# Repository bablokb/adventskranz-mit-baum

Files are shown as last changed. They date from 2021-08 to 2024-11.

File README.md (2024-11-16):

Adventskranz mit Baumornament
=============================

In diesem Projekt geht es um einen Adventskranz aus dem 3D-Drucker.
Statt Kerzen kommen Baum-Ornamente zum Einsatz.

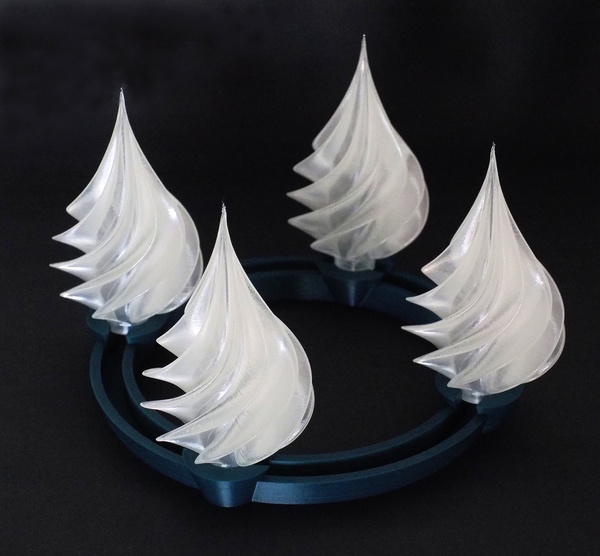
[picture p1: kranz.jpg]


3D-Modelle
----------

Das Modell des Baums (`3D/Ornament.stl.gz`) ist von
<https://www.thingiverse.com/thing:2705104>. Mein Remix
(`3D/Ornament-mit-Basis.stl.gz`) fügt einen
kleinen Stamm hinzu sowie ein Loch im Boden. Das dazugehörige
OpenScad-Programm gibt es auch im Verzeichnis `3D`.
N.B: beide STL-Dateien sind mit gzip komprimiert.

Gedruckt ist das Ornament im Vasenmodus mit naturfarbenem PET. Die
Druckdauer beträgt ca. 2 Stunden pro Ornament (0.2mm Schichtdicke).

Der Kranz ist mit OpenScad entworfen und benötigt 6 Stunden Druckzeit.
Zusätzlich gibt es noch Abdeckungen für die Kabelkanäle. Davon
sind vier notwendig, eine Abdeckung hat einen passenden Ausschnitt
für die Kabelzuführung.

Die Toleranzen sind sehr gering, je nach Drucker und Material
ist hier eine Anpassung notwendig. Dank OpenScad ist das auch
ohne große Vorkenntnisse leicht möglich.

Hardware-Setup
--------------

Das Projekt verwendet diffuse 8mm Neopixels von Adafruit, siehe
<https://www.adafruit.com/product/1734>. Ähnliche LEDs gibt es
auch auf eBay. Die Ansteuerung ist i.a.R. gleich, das Pinout
aber nicht.

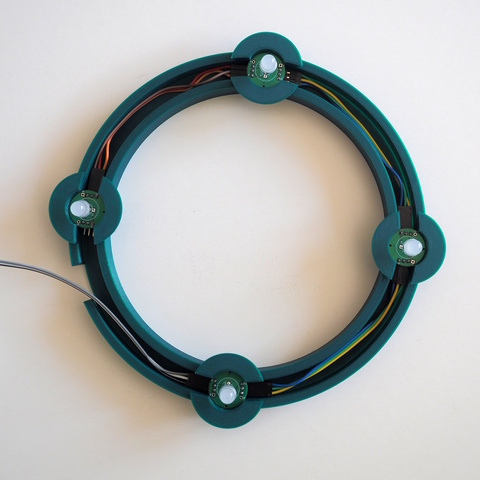
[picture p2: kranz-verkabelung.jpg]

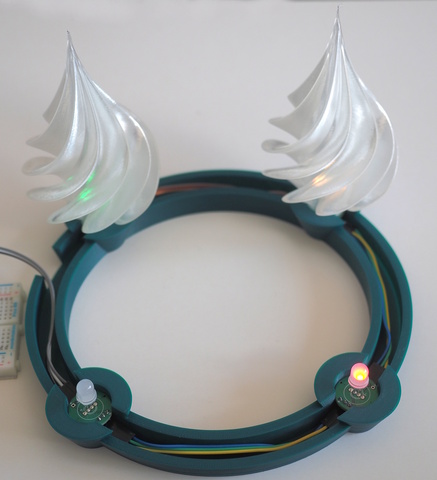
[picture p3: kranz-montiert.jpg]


Jedes Pixel benötigt einen 100nF-Kondensator, das erste Pixel
zusätzlich noch einen 300 Ohm Widerstand in der Datenleitung.

Neopixel benötigen normalerweise 5V (Versorgungsspannung und auf
der Datenleitung). Bei vier Pixel funktioniert es aber i.a.R. auch
mit 3V3. Alle Details zu Neopixel gibt es in dem umfassenden
Handbuch von Adafruit
(<https://learn.adafruit.com/adafruit-neopixel-uberguide>).

Platine
-------

Im Verzeichnis `pcb` gibt es die KiCAD-Quellen für eine passende
Platine. Die Dimensionen der Platine sind exakt auf den Kranz
abgestimmt. Die Miniplatine enthält den Kondensator und den
Widerstand, wobei das Layout so ist, dass die Platine mit oder
ohne Widerstand verwendet werden kann.

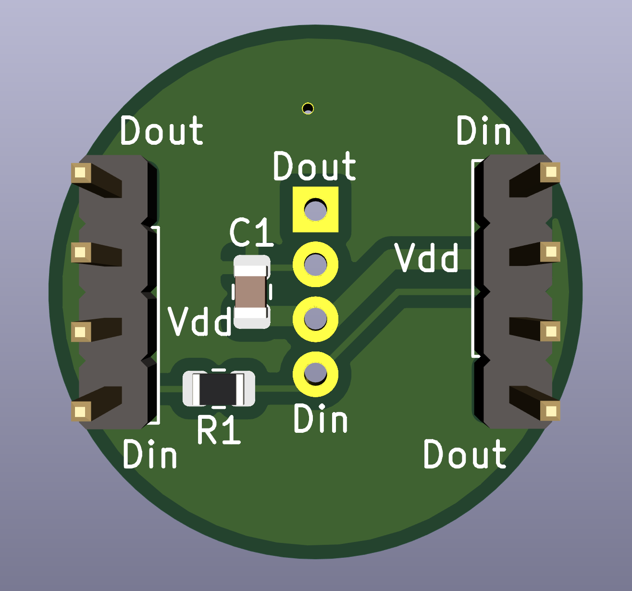
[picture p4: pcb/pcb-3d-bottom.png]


Python-Quellen
--------------

Das Verzeichnis `src_python_btn` enthält ein CircuitPython-Programm für
die Steuerung. Das Programm verwendet einen Taster für das Schalten
der LEDs.

Eine Alternativimplementation ist im Verzeichnis `src_python_sr04`.
Hier kommt ein Distanz-Sensor (HC-SR04) statt des Tasters zum Einsatz.

Eine weitere Alternative ist im Verzeichnis `src_python_touch`
vorhanden. Das Beispiel verwendet die direkte Touch-Unterstützung
durch einen Pin des Mikrokontrollers.

Die vom Projekt mitgelieferten Libs sind auf dem 9.x-Stand und mit
Circuit-Python 9.2.0 mit dem Trinket-M0 getestet.

Attiny85-Quellen
----------------

Im Verzeichnis `src_attiny85` gibt es den Quellcode als C-Programm.

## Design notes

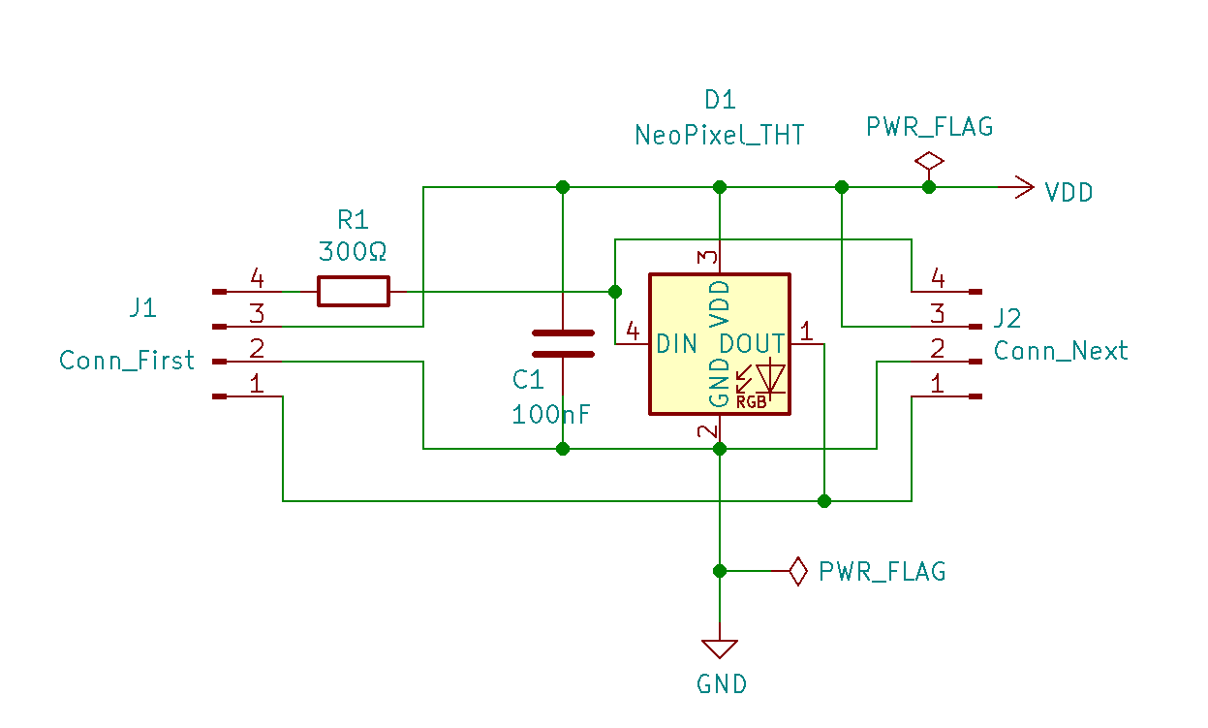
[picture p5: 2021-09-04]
pcb/schematic.png

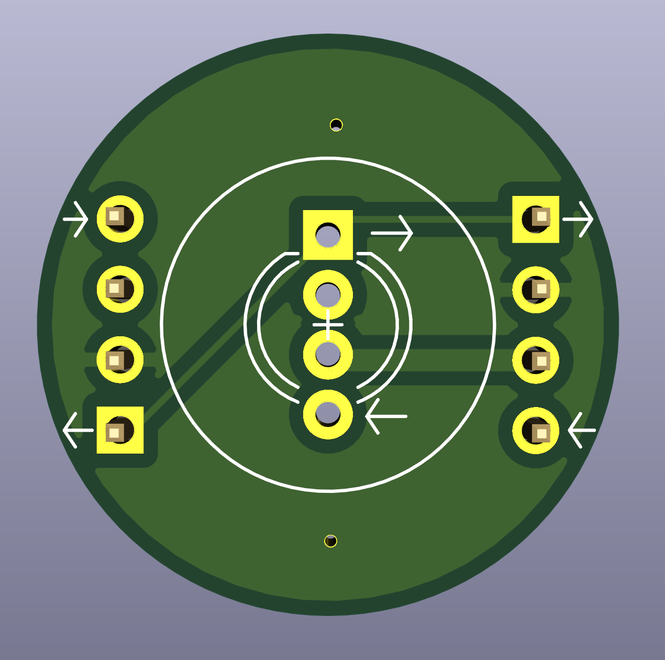
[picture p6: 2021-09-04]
pcb/pcb-3d-top.png

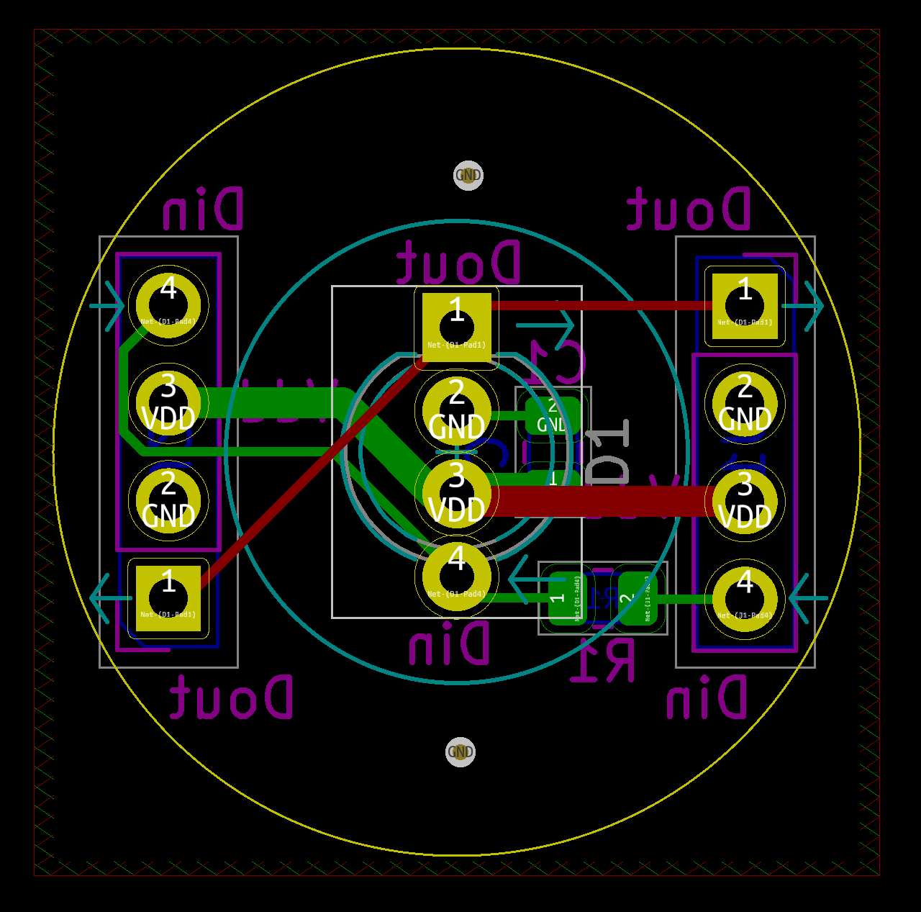
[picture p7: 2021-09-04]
pcb/layout.png

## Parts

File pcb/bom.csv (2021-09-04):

Comment | Designator | Footprint | LCSC
100nF | C1 | Capacitor_SMD:C_0805_2012Metric | C49678
NeoPixel_THT | D1 | LED_THT:LED_D5.0mm-4_RGB_Wide_Pins
Conn_First | J1 | Connector_PinHeader_2.54mm:PinHeader_1x04_P2.54mm_Vertical
Conn_Next | J2 | Connector_PinHeader_2.54mm:PinHeader_1x04_P2.54mm_Vertical
300Ω | R1 | Resistor_SMD:R_0805_2012Metric | C17617

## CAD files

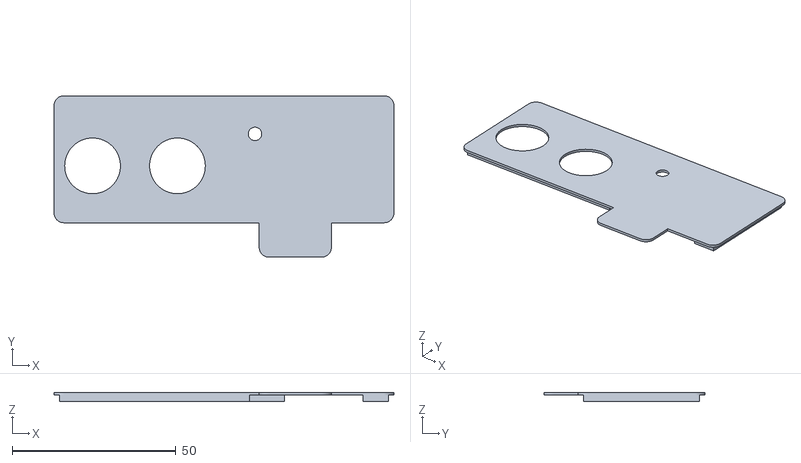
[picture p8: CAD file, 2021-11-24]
3D/steuerung-cover.stl
103.7 x 49.2 x 2.80

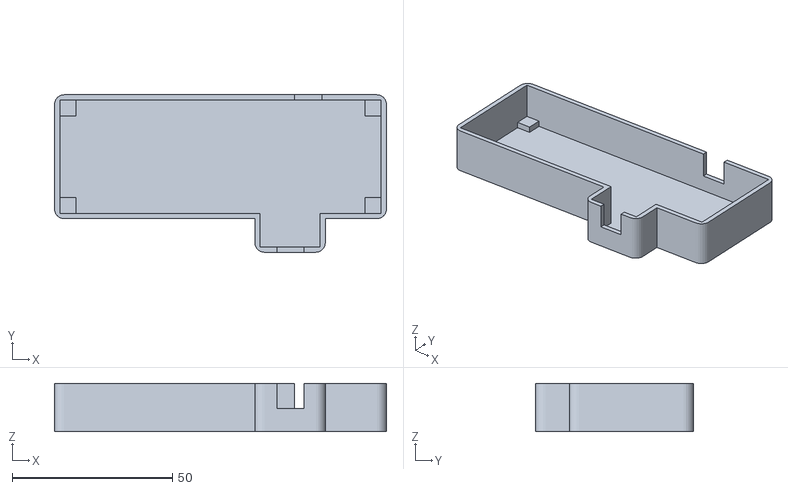
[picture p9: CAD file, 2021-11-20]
3D/steuerung.stl
103.7 x 49.2 x 15.0

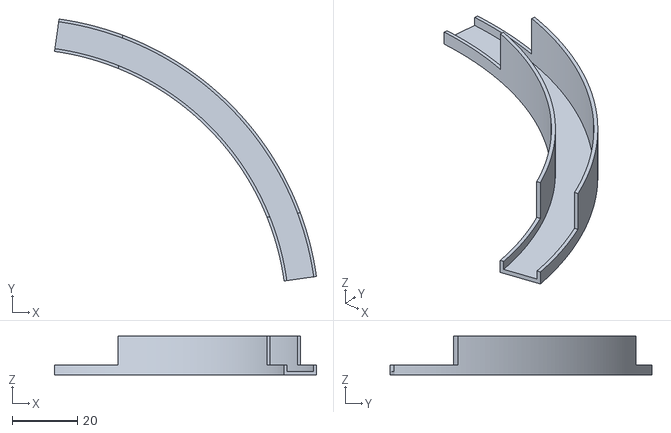
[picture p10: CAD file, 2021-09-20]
3D/abdeckung.stl
80.0 x 80.0 x 11.9

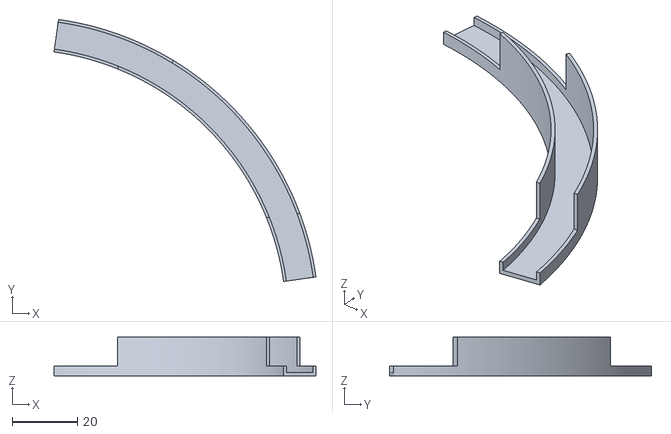
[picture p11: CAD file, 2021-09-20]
3D/abdeckung-mit-ausschnitt.stl
80.0 x 80.0 x 11.9

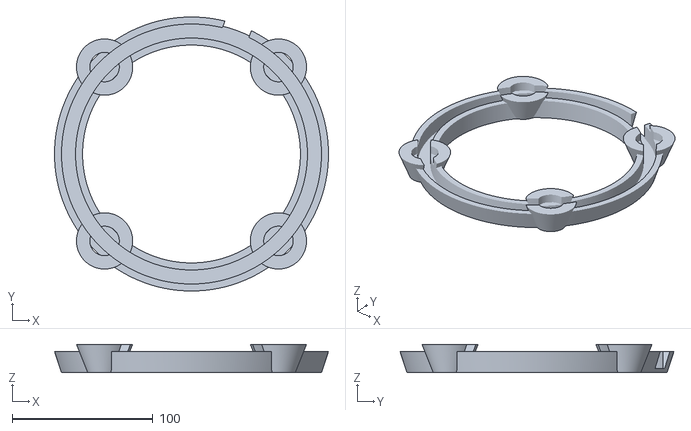
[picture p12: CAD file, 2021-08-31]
3D/kranz.stl
195.0 x 195.0 x 20.0

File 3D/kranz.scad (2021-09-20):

// -----------------------------------------------------------------------------
// 3D-Model (OpenSCAD) Adventskranz.
//
// Author: Bernhard Bablok
// License: GPL3
//
// Website: https://github.com/bablokb/pcb-adventskranz
//
// -----------------------------------------------------------------------------

$fa = 1;
$fs = 0.4;

fuzz = 0.001;

k_b   = 3;             // base
k_h   = 15;            // height
kr_o  = 195/2;         // outer radius
kr_w  = 20;            // width
kr_i  = kr_o - kr_w;   // inner radius
kr_c  = 10;            // cutout-width
k_fac = 0.95;          // slimify-factor
p_h   = 1.6;           // pcb-height

b_h   = 5;             // base height
br_o  = 20;            // base outer radius
br_i  = 10.5;          // base inner radius
b_fac = 0.6;           // slimify-factor (> br_i/br_o)


// --- Generisches Ring Modul   ----------------------------------------------
// Der Faktor gibt an, um wieviel sich die Breite nach unten verjüngt

module ring(o,i,h,fac=1) {
  difference() {
    cylinder(h,o*fac,o);
    translate([0,0,-fuzz]) cylinder(h+2*fuzz,i,i);
  }
}

// --- Basis des Kranz   -----------------------------------------------------
// zusammengesetzt aus einem großen Ring und vier Ringen für die Kerzen

module basis() {
  ring(kr_o,kr_i,k_h,fac=k_fac);
  translate([kr_i+kr_w/2,0,0])  ring(br_o,br_i,k_h+b_h,fac=b_fac);
  translate([-kr_i-kr_w/2,0,0]) ring(br_o,br_i,k_h+b_h,fac=b_fac);
  translate([0,kr_i+kr_w/2,0])  ring(br_o,br_i,k_h+b_h,fac=b_fac);
  translate([0,-kr_i-kr_w/2,0]) ring(br_o,br_i,k_h+b_h,fac=b_fac);
}

// --- Kranz   ---------------------------------------------------------------
// Zusätzliche Ausschnitte für die Platinen je Kerzenhalter sowie
// einem 360°-Kabelkanal

module kranz() {
  difference() {
    basis();
    translate([kr_i+kr_w/2,0,k_h-p_h])  cylinder(b_h+p_h+fuzz,br_i,br_i);
    translate([-kr_i-kr_w/2,0,k_h-p_h]) cylinder(b_h+p_h+fuzz,br_i,br_i);
    translate([0,kr_i+kr_w/2,k_h-p_h])  cylinder(b_h+p_h+fuzz,br_i,br_i);
    translate([0,-kr_i-kr_w/2,k_h-p_h]) cylinder(b_h+p_h+fuzz,br_i,br_i);
    // Kabelkanal
    translate([0,0,k_b]) ring(kr_o-(kr_w-kr_c)/2,kr_i+(kr_w-kr_c)/2,k_h+b_h+fuzz);
    // Ausschnitt für Anschluss
    rotate([0,0,25]) translate([kr_i+6,-10,k_b]) cube([30,20,30]);
  }
}

// --- Abdeckung Kabelkanal   ------------------------------------------------

module cover(anschluss=false) {
  delta  = 0.1;                     // Verkleinerung für Passgenauigkeit
  k      = (kr_w-kr_c)/2 - 2*delta; // (Breite Ring - Breite Cutout)/2
  d = k_h - k_b - delta;            // Cutout-Depth (Höhe - Basis)
  w2 = 0.86;                        // Wanddicke, 2 Schichten
  c_b = 1;                          // Basis Cover
  winkel = 8;                       // Abstand in Grad zur Achse

  points = [
    [delta + kr_i+k,     0],
    [delta + kr_i+k+kr_c,0],
    [delta + kr_i+k+kr_c,d],
    [delta + kr_i+k+kr_c-w2,d],
    [delta + kr_i+k+kr_c-w2,c_b],
    [delta + kr_i+k+w2,c_b],
    [delta + kr_i+k+w2,d],
    [delta + kr_i+k,d]
    ];
  difference() {
    rotate([0,0,winkel]) rotate_extrude(angle=90-2*winkel) polygon(points);
    rotate([0,0,winkel]) translate([kr_i,-10,k_b]) cube([30,30,30]);
    rotate([0,0,90-winkel]) translate([kr_i,-20,k_b]) cube([30,30,30]);
    if (anschluss) {
      rotate([0,0,90-25]) translate([kr_i+6,-10,k_b]) cube([30,20,30]);
    }
  }
}

// --- Ausschnitte für Testdruck   -------------------------------------------

//intersection() {
//  rotate([0,0,45]) kranz();
//  translate([10,40,0]) cube(90);
//}

//intersection() {
//  cover(true);
//  translate([70,0,0]) cube(90);
//}

// --- Test für Kabelkanalabdeckung   ----------------------------------------

//rotate([0,0,45]) color("blue") translate([0,0,k_h]) mirror([0,0,90]) cover(true);

// --- Finale Objekte   ------------------------------------------------------

// rotate([0,0,45]) kranz();       // kompletter Kranz, gedreht wg. Druckbett
// cover();                        // Abdeckung Kabelkanal ohne Ausschnitt
   cover(true);                    // Abdeckung Kabelkanal mit  Ausschnitt

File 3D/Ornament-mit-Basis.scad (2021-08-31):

$fa = 1;
$fs = 0.4;

fuzz = 0.001;

difference() {
  union() {
    translate([-0.225,0.525,5]) import("Ornament.stl");
    cylinder(5+fuzz,10.5,10.5);
  }
  translate([0,0,-1]) cylinder(10,6,6);
}

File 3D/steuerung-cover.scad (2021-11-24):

// -----------------------------------------------------------------------------
// 3D-Model (OpenSCAD) Abdeckung Steuermodul.
//
// Author: Bernhard Bablok
// License: GPL3
//
// Website: https://github.com/bablokb/pcb-adventskranz
//
// -----------------------------------------------------------------------------

include <BOSL2/std.scad>

$fa = 1;
$fs = 0.4;
$fn = 64;
//$fn = 24;

fuzz = 0.001;

// dimensions
w4 = 1.67;           // wall 4 layers
w2 = 0.86;           // wall 2 layers
d  = 0.2;            // delta

x_pcb = 100;         // pcb dimensions
y_pcb = 35;
//h_pcb = 10;
h_pcb = 2;

x_85     = 18.3;     // attiny85 dimensions
y_85     = 24.1;
x_off_85 = 62.8;     // offset of attiny85
y_off_85 = 10.3;

x_off_pins = 73.5;

r = 3;               // edges 3mm rounding
//b = 1.2;             // bottom-plate
b = 0.8;             // bottom-plate

r_sen       = 8.0;   // sensor radius
r_sen_d     = 0.5;   // extra space for sensor
x_off_sen_1 = 1.9;   // x-offset from wall
x_off_sen_2 = 27.8;  // x-offset from wall
y_off_sen   = 7.5;   // y-offset from wall

r_but     = 3.5/2;   // button radius
r_but_d   = 0.3;     // extra space for button
x_off_but = 57.7;    // x-offset from wall
y_off_but = 23.5;    // y-offset from wall


// --- inner void   --------------------------------------------------------------

module inner() {
  difference() {
    // walls
    union() {
      cuboid([x_pcb+2*d,y_pcb+2*d,h_pcb], p1=[-d,-d,-h_pcb+fuzz]);                      // pcb
      cuboid([x_85+2*d,y_85+2*d,h_pcb], p1=[-d+x_off_85-d,-d-y_off_85-d,-h_pcb+fuzz]);  // attiny85
    }
    // inner void
    union() {
      cuboid([x_pcb+2*d-2*w2,y_pcb+2*d-2*w2,h_pcb], p1=[-d+w2,-d+w2,-h_pcb+fuzz]);      // pcb
      cuboid([x_85+2*d-2*w2,y_85+2*d+w2,h_pcb], 
              p1=[-d+x_off_85-d+w2,-d-y_off_85-d+w2,-h_pcb+fuzz]);                     // attiny85
    }
    // remove additional walls
    cuboid([20,y_pcb+2*d-2*w2,h_pcb], p1=[-5,-d+w2,-h_pcb+fuzz]);         // left
    cuboid([x_pcb-w2-w4-x_off_85,y_85+2*d,h_pcb],
            p1=[x_off_85-5,-d-y_off_85-d,-h_pcb+fuzz]);                   // front attiny85
    cuboid([x_pcb-w2-w4-x_off_pins,20,h_pcb],
            p1=[x_off_pins-5,y_pcb-5,-h_pcb+fuzz]);                   // front attiny85
    
  } 
}

// --- outer shell   ------------------------------------------------------------

module outer() {
  cuboid(
      [x_pcb+2*d+2*w4,y_pcb+2*d+2*w4,b], p1=[-d-w4,-d-w4,0],
      rounding=r,
      edges=[LEFT+FRONT,RIGHT+FRONT,LEFT+BACK,RIGHT+BACK]
  );
  cuboid(
      [x_85+2*d+2*w4,y_85+2*d+2*w4,b], p1=[-d+x_off_85-d-w4,-d-y_off_85-d-w4,0],
      rounding=r,
      edges=[LEFT+FRONT,RIGHT+FRONT,LEFT+BACK,RIGHT+BACK]
  );
}

difference() {
  outer();
  translate([x_off_sen_1+r_sen,r_sen+y_off_sen,-fuzz])
                                      cylinder(b+2*fuzz,r1=r_sen+r_sen_d,r2=r_sen+r_sen_d);
  translate([x_off_sen_2+r_sen,r_sen+y_off_sen,-fuzz])
                                      cylinder(b+2*fuzz,r1=r_sen+r_sen_d,r2=r_sen+r_sen_d);
  translate([x_off_but+r_but,r_but+y_off_but,-fuzz])
                                      cylinder(b+2*fuzz,r1=r_but+r_but_d,r2=r_but+r_but_d);
}
inner();

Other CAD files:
3D/steuerung-m0.scad
3D/steuerung.scad

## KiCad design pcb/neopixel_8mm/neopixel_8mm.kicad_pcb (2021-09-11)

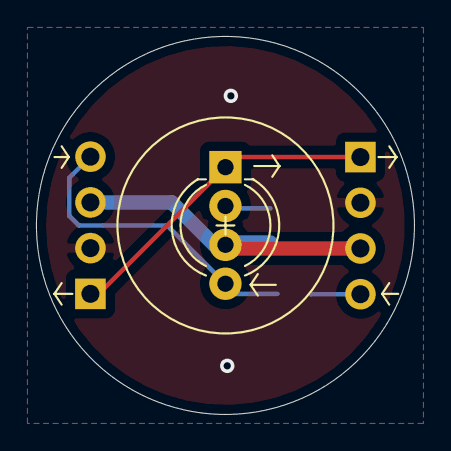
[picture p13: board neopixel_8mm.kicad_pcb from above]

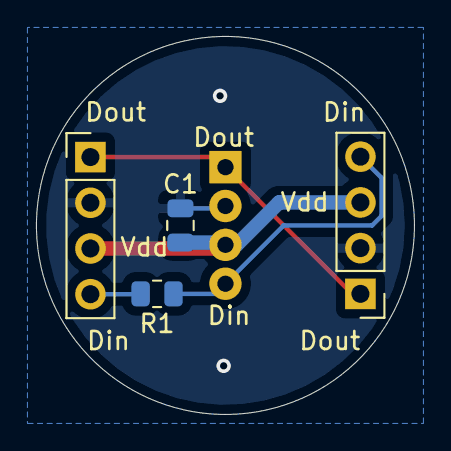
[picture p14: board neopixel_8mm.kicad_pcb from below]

Board: 2 copper layers, 21.0 x 21.0 mm, 5 parts (4 on the bottom side), 5 nets.

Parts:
C1: C; C_0805_2012Metric
D1: NeoPixel_THT; LED_D5.0mm-4_RGB_Wide_Pins
J1: Conn_First; PinHeader_1x04_P2.54mm_Vertical
J2: Conn_Next; PinHeader_1x04_P2.54mm_Vertical
R1: R; R_0805_2012Metric

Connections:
GND: C1.2, D1.2, J1.2, J2.2
unnamed: D1.1, J1.1, J2.1
unnamed: D1.4, J2.4, R1.1
unnamed: J1.4, R1.2
VDD: C1.1, D1.3, J1.3, J2.3

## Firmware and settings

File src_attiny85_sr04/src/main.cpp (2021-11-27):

// ---------------------------------------------------------------------------
// Control four neopixels with a HC-SR04 ultrasonic sensor:
// cycle through 0-1-2-3-4-0 active pixels. All pixels have the same color.
//
// Note there is an additional button to turn the pixels on/off without
// changing the number of active pixels.
//
// Author: Bernhard Bablok
// License: GPL3
//
// Website: https://github.com/bablokb/adventskranz-mit-baum
//
// Note: this is an adapted example from Adafruit's neopixel-lib
// ---------------------------------------------------------------------------

#include <Arduino.h>
#include <EEPROM.h>
#include <Adafruit_NeoPixel.h>
#include <NewPing.h>

void update_pixel(void);
uint32_t wheel(byte pos);

// --- settings   ------------------------------------------------------------

#define NEO_PIN 0     // connected to data-in
#define LED_PIN 1     // on board LED
#define BTN_PIN 2     // button
#define TRG_PIN 3     // SR04 trigger pin
#define ECHO_PIN 4    // SR05 echo pin
#define NUMPIXELS 4   // number of pixels
#define BRIGHTNESS 50 // pin-brightness: 0-255 (not linear)
#define DELAY 300     // delay in ms
#define EEPROM_ADR 0  // eeprom address to use
#define DISTANCE 30   // distance in cm to check 

// --- objects   -------------------------------------------------------------

Adafruit_NeoPixel strip = Adafruit_NeoPixel(NUMPIXELS, NEO_PIN,
                                            NEO_RGB + NEO_KHZ800);
NewPing sonar(TRG_PIN, ECHO_PIN);

byte counter, global_state, sonar_state, col_pos;
uint32_t color;

// --- setup of objects   ----------------------------------------------------

void setup() {
  pinMode(BTN_PIN, INPUT_PULLUP);
  pinMode(LED_PIN,OUTPUT);
  digitalWrite(LED_PIN,LOW);
  counter = EEPROM.read(EEPROM_ADR);
  counter = counter > 4 ? 0 : counter;
  global_state = 0;
  sonar_state = 0;
  col_pos = 0;
  strip.begin();
  strip.setBrightness(BRIGHTNESS);
  strip.show(); // initialize all pixels to 'off'
}

// --- main loop   -----------------------------------------------------------

void loop() {
  while (true) {
    update_pixel();

    if (digitalRead(BTN_PIN) == LOW) {
      global_state = 1 - global_state;
      if (!global_state) {
        // turned off, save counter in eeprom
        EEPROM.write(EEPROM_ADR,counter);
      }
      digitalWrite(LED_PIN,global_state);
      delay(DELAY); // debounce
      continue;
    }

    // idle loop if state is off
    if (!global_state) {
      continue;
    }

    // check "on"-event, i.e. distance < DISTANCE
    if (!sonar_state && sonar.convert_cm(sonar.ping_median()) < DISTANCE) {
      sonar_state = 1;
      counter = (counter + 1) % 5;  // event detected, update counter
      continue;
    }

    // check "off"-event, i.e. distance > DISTANCE
    if (sonar_state && sonar.convert_cm(sonar.ping_median()) > DISTANCE) {
      sonar_state = 0;
    }
  }
}

// --- pixel-update   --------------------------------------------------------

void update_pixel(void) {
  // update color
  col_pos = col_pos + 1;     // this is %256, since col_pos is a byte
  color = wheel(col_pos);

  // update pixels
  for (int i = 0; i < NUMPIXELS; ++i) {
    if (i < counter && global_state) {
      strip.setPixelColor(i, color);
    } else {
      strip.setPixelColor(i, 0);
    }
  }
  strip.show();
}

// --- get color from the color wheel   --------------------------------------
// Input a value 0 to 255 to get a color value.
// The colours are a transition r - g - b - back to r.

uint32_t wheel(byte pos) {
  pos = 255 - pos;
  if (pos < 85) {
    return strip.Color(255 - pos * 3, 0, pos * 3);
  }
  if (pos < 170) {
    pos -= 85;
    return strip.Color(0, pos * 3, 255 - pos * 3);
  }
  pos -= 170;
  return strip.Color(pos * 3, 255 - pos * 3, 0);
}

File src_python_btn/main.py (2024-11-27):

#!/usr/bin/python3
# --------------------------------------------------------------------------
# Control four neopixels with a button: cycle through 0-1-2-3-4-0 active
# pixels. All pixels have the same color.
#
# Author: Bernhard Bablok
# License: GPL3
#
# Website: https://github.com/bablokb/adventskranz-mit-baum
#
# Note: color-wheel code from the neopixel-sample from Adafruit
# --------------------------------------------------------------------------

import time
import board
import digitalio
import neopixel
import adafruit_fancyled.adafruit_fancyled as fancy

LEVELS = [round(0.1*i,1) for i in range(0,11)]

# values for Pimoroni Plasma2040
PIN_NEO = board.DATA
NUM_NEO = 4
ORD_NEO = neopixel.RGB
LVL_NEO = 7               # index into brightness-levels
INT_NEO = 5               # update interval for colors
PIN_BTN = board.SW_A
PIN_LVL = board.SW_B
INT_BTN = 0.5             # button delay interval (debounce)
LED     = board.LED_R     # board led
LED_ON  = False           # active low LED

# values for Pico
# PIN_NEO = board.GP18
# NUM_NEO = 4
# ORD_NEO = neopixel.GRB
# LVL_NEO = 2               # index into brightness-levels
# INT_NEO = 1               # update interval for colors
# PIN_BTN = board.GP14
# PIN_LVL = board.GP15
# INT_BTN = 0.5             # button delay interval (debounce)
# LED     = board.LED       # board led
# LED_ON  = True            # active high LED

# --- objects   -------------------------------------------------------------

# list of neo-pixel-objects
pixels = neopixel.NeoPixel(
  PIN_NEO, NUM_NEO, brightness=LEVELS[LVL_NEO],
  auto_write=False, pixel_order=ORD_NEO)
time.sleep(1)

# button
btn           = digitalio.DigitalInOut(PIN_BTN)
btn.switch_to_input(pull=digitalio.Pull.UP)
lvl           = digitalio.DigitalInOut(PIN_LVL)
lvl.switch_to_input(pull=digitalio.Pull.UP)

# led
led = digitalio.DigitalInOut(LED)
led.switch_to_output(value = not LED_ON)

# --- colorwheel   -----------------------------------------------------------

def wheel(pos):
  # Input a value 0 to 255 to get a color value.
  # The colours are a transition r - g - b - back to r.
  if pos < 0 or pos > 255:
    r = g = b = 0
  elif pos < 85:
    r = int(pos * 3)
    g = int(255 - pos * 3)
    b = 0
  elif pos < 170:
    pos -= 85
    r = int(255 - pos * 3)
    g = 0
    b = int(pos * 3)
  else:
    pos -= 170
    r = 0
    g = int(pos * 3)
    b = int(255 - pos * 3)
  return (r, g, b) if ORD_NEO in (neopixel.RGB, neopixel.GRB) else (r, g, b, 0)


# --- main loop   -----------------------------------------------------------

counter     = 0
brit_index  = LVL_NEO
col_pos     = None
last_btn    = 0
last_update = -INT_NEO

while True:
  # update counter on button press
  if not btn.value and time.monotonic() > last_btn + INT_BTN:
    last_btn = time.monotonic()
    # pseudo-random initial color-value at very first button press
    if col_pos is None:
      col_pos = time.monotonic_ns() % 256
    counter = (counter+1)%(NUM_NEO+1)
    led.value = LED_ON
    time.sleep(0.2)
    led.value = not LED_ON

  # update brightness-level on button press
  if not lvl.value and time.monotonic() > last_btn + INT_BTN:
    last_btn = time.monotonic()
    brit_index = 1 + brit_index%10
    pixels.brightness = LEVELS[brit_index]
    color_adj = fancy.gamma_adjust(fancy.CRGB(*color),gamma_value=2.2,
                                   brightness=LEVELS[brit_index]).pack()
    led.value = LED_ON
    time.sleep(0.2)
    led.value = not LED_ON

  # update color after INT_NEO seconds
  if counter and time.monotonic() > last_update + INT_NEO:
    # update color
    last_update = time.monotonic()
    col_pos     = (col_pos+1)%256
    color       = wheel(col_pos)
    color_adj = fancy.gamma_adjust(fancy.CRGB(*color),gamma_value=2.2,
                                   brightness=LEVELS[brit_index]).pack()
  # update pixels
  if counter:
    for i in range(NUM_NEO):
      pixels[i] = color_adj if i<counter else (0,0,0)
  else:
    pixels.fill(0)
  pixels.show()
  time.sleep(0.1)

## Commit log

2021-08-31 added some comments
    [kranz.scad]
2021-08-31 fixed reference to stl
2021-09-04 pack stl in zip
2021-09-04 document stl within zip
2021-09-07 added cover
    [kranz.scad]
2021-09-09 fixed postion of cutout on cover
    [kranz.scad]
2021-09-11 updated project-url
    [neopixel_8mm.kicad_pcb, neopixel_8mm.sch]
2021-09-20 optimzed cover
    [kranz.scad]
2021-09-30 bugfix: remove delay during idle
    [main.cpp]
2021-11-05 save current counter to eeprom
2021-11-18 reduced y-offset for attiny85
    [steuerung.scad]
2021-11-18 sd-cutout 1mm lower
    [steuerung.scad]
2021-11-18 increased x-dim for attiny85 by 0.3mm
    [steuerung.scad]
2021-11-24 fixed cutout sizes and offsets
    [steuerung-cover.scad]
2021-11-27 added macro for distance-check, set to 30cm
2024-11-19 blink board-LED when touch detected
2024-11-19 exclude stl-files
2024-11-19 case for Trinket-M0
    [steuerung-m0.scad]
2024-11-21 support second button to change brightness
